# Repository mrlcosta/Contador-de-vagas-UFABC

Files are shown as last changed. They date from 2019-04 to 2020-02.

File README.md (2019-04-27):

Este projeto tem o propósito de auxiliar e humanizar o trabalho dos funcionários da portaria. 
A situação atual é: um senhor de idade avançada que fica encarregado de fazer a contagem de aproximadamente 150 vagas em um caderninho, precisa colocar e tirar o cone para impedir a passagem de carros (embaixo de sol e chuva) e também escuta reclamação de aluno dizendo que as vagas estão sendo contadas erradas (há diversos posts no grupo também).

O projeto é simples: o sensor conta quantos carros entram e quantos carros saem. 
Quando o estacionamento estiver cheio, a fita de led mudará de verde para vermelho.

Assim o senhor da portaria poderá ficar dentro de sua sala apenas verificando as carteirinhas.
Peço a colaboração de todos.

**CONTRIBUIÇÃO**

O projeto aceita contribuição e é open source, porém você precisa seguir as regras abaixo:

Testar bem antes de colocar em prod. Você precisa abranger muitos fatores e todo código deve ser rigorosamente testado para ter o pull request aceito.

O projeto deve possuir o mínimo de boas práticas de código e prezar pelo entendimento alheio. No futuro outras pessoas irão dar manutenção nele, seja gentil.

OBS: A ideia inicial era apenas usar o github como plataforma de versionamento, não imaginei que muitas pessoas gostariam de contribuir, portanto a documentação ainda está muito precária. Estou atualizando aos poucos para que todos possam entender melhor.

A escolha do chip talvez não tenha sido a melhor em questões de popularidade, porém pode ser interessante aprender a mexer em outro microcontrolador. Quem quiser me chamar para perguntar como instala os programas utilizados, compilador, onde conseguir o chip, etc Estarei a disposição. Em breve será documentado.

Muitas pessoas adoram o arduino por ser de fácil acesso, conter muito material didático e as vezes ele acaba ficando na nossa zona de conforto. É interessante levar também para nossa universidade a diversidade de outras ferramentas que não a utilização de arduino, tudo bem? não se sinta acanhado com isto, estamos aqui para expandir nossos horizontes.

**FUNCIONAMENTO BASICO**

Ficará um sensor no portão de entrada e outro no portão de saída.
Quando o sensor detectar que tem um obstáculo na portaria, ele conta ou subtrai uma vaga.
para diferenciar acionamento de humanos ou carros passando o algoritmo de debounce foi implementado.
A cada atualização do numero de carros, o número é atualizado na eeprom para evitar percas por desligamento.
A gravação da eeprom da eeprom é feita de forma rotativa pois ela tem vida útil limitada.

**MATERIAIS MINIMOS**

sensor: http://www.baudaeletronica.com.br/sensor-de-proximidade-infravermelho-e18-d80nk.html

display LCD: http://www.baudaeletronica.com.br/display-lcd-16x2-azul.html

microcontrolador: https://produto.mercadolivre.com.br/MLB-1218797200-modulo-desenvolvimento-microcontrolador-st-stm8-stm8s003f3p6-_JM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

gravador/debuger: https://produto.mercadolivre.com.br/MLB-1132196907-programador-stm32-stm8-stlink-st-link-v2-mini-_JM

A placa irá comutar a fita de led através de um TIP41.

A caixa plastica é um modelo da patola: PB107.

Os botões de navegação são 3 push button.

Dúvidas? Sugesões? fala comigo: mrlcosta0@gmail.com

Seu feedback e engajamento é muito importante pra mim.

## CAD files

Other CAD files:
firmware/ac01.stp
firmware/ac01_Programmer/ac01_STVP.stp

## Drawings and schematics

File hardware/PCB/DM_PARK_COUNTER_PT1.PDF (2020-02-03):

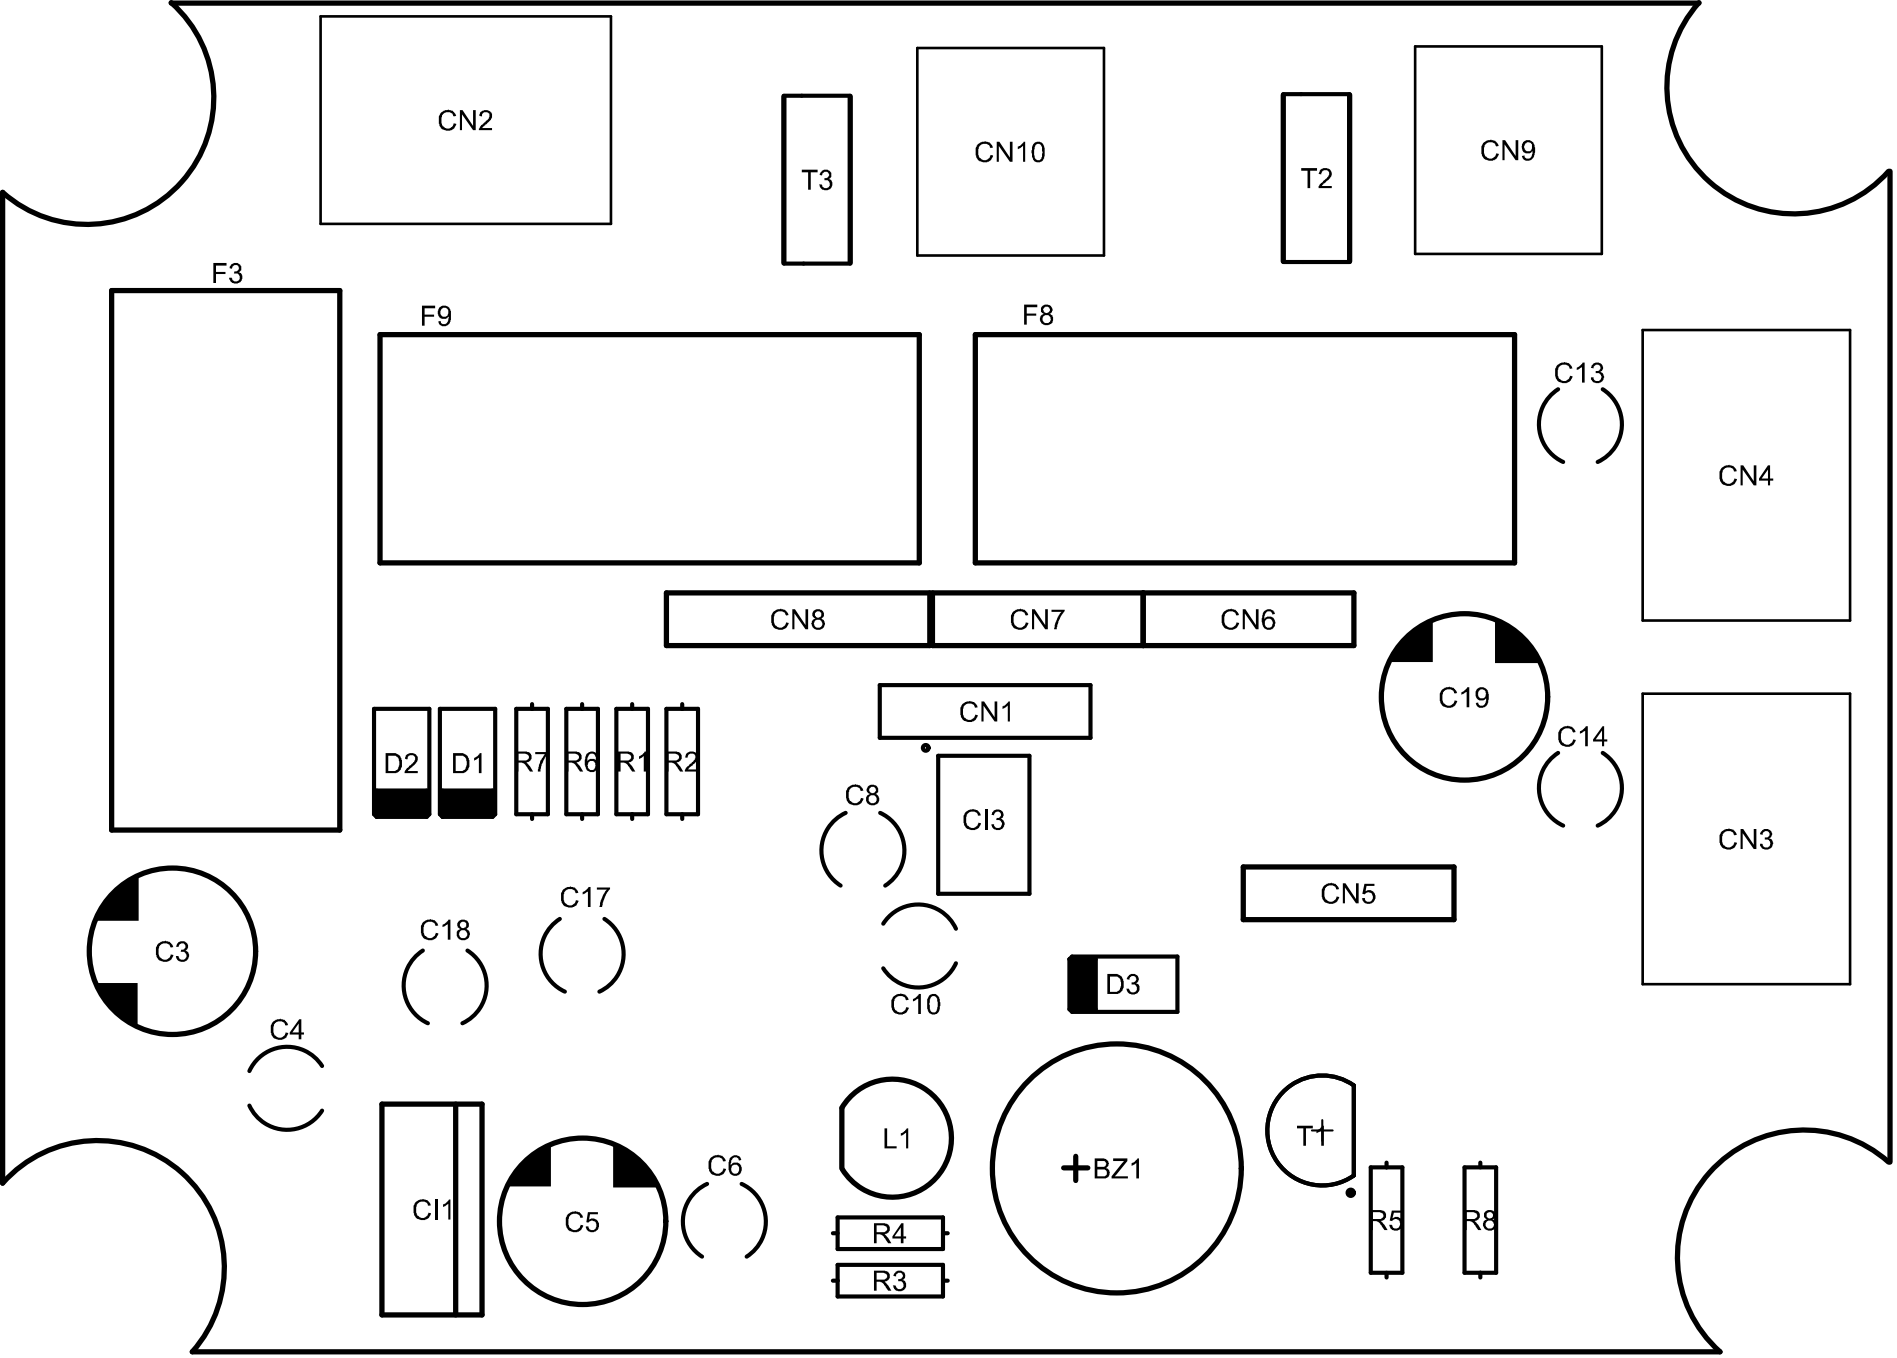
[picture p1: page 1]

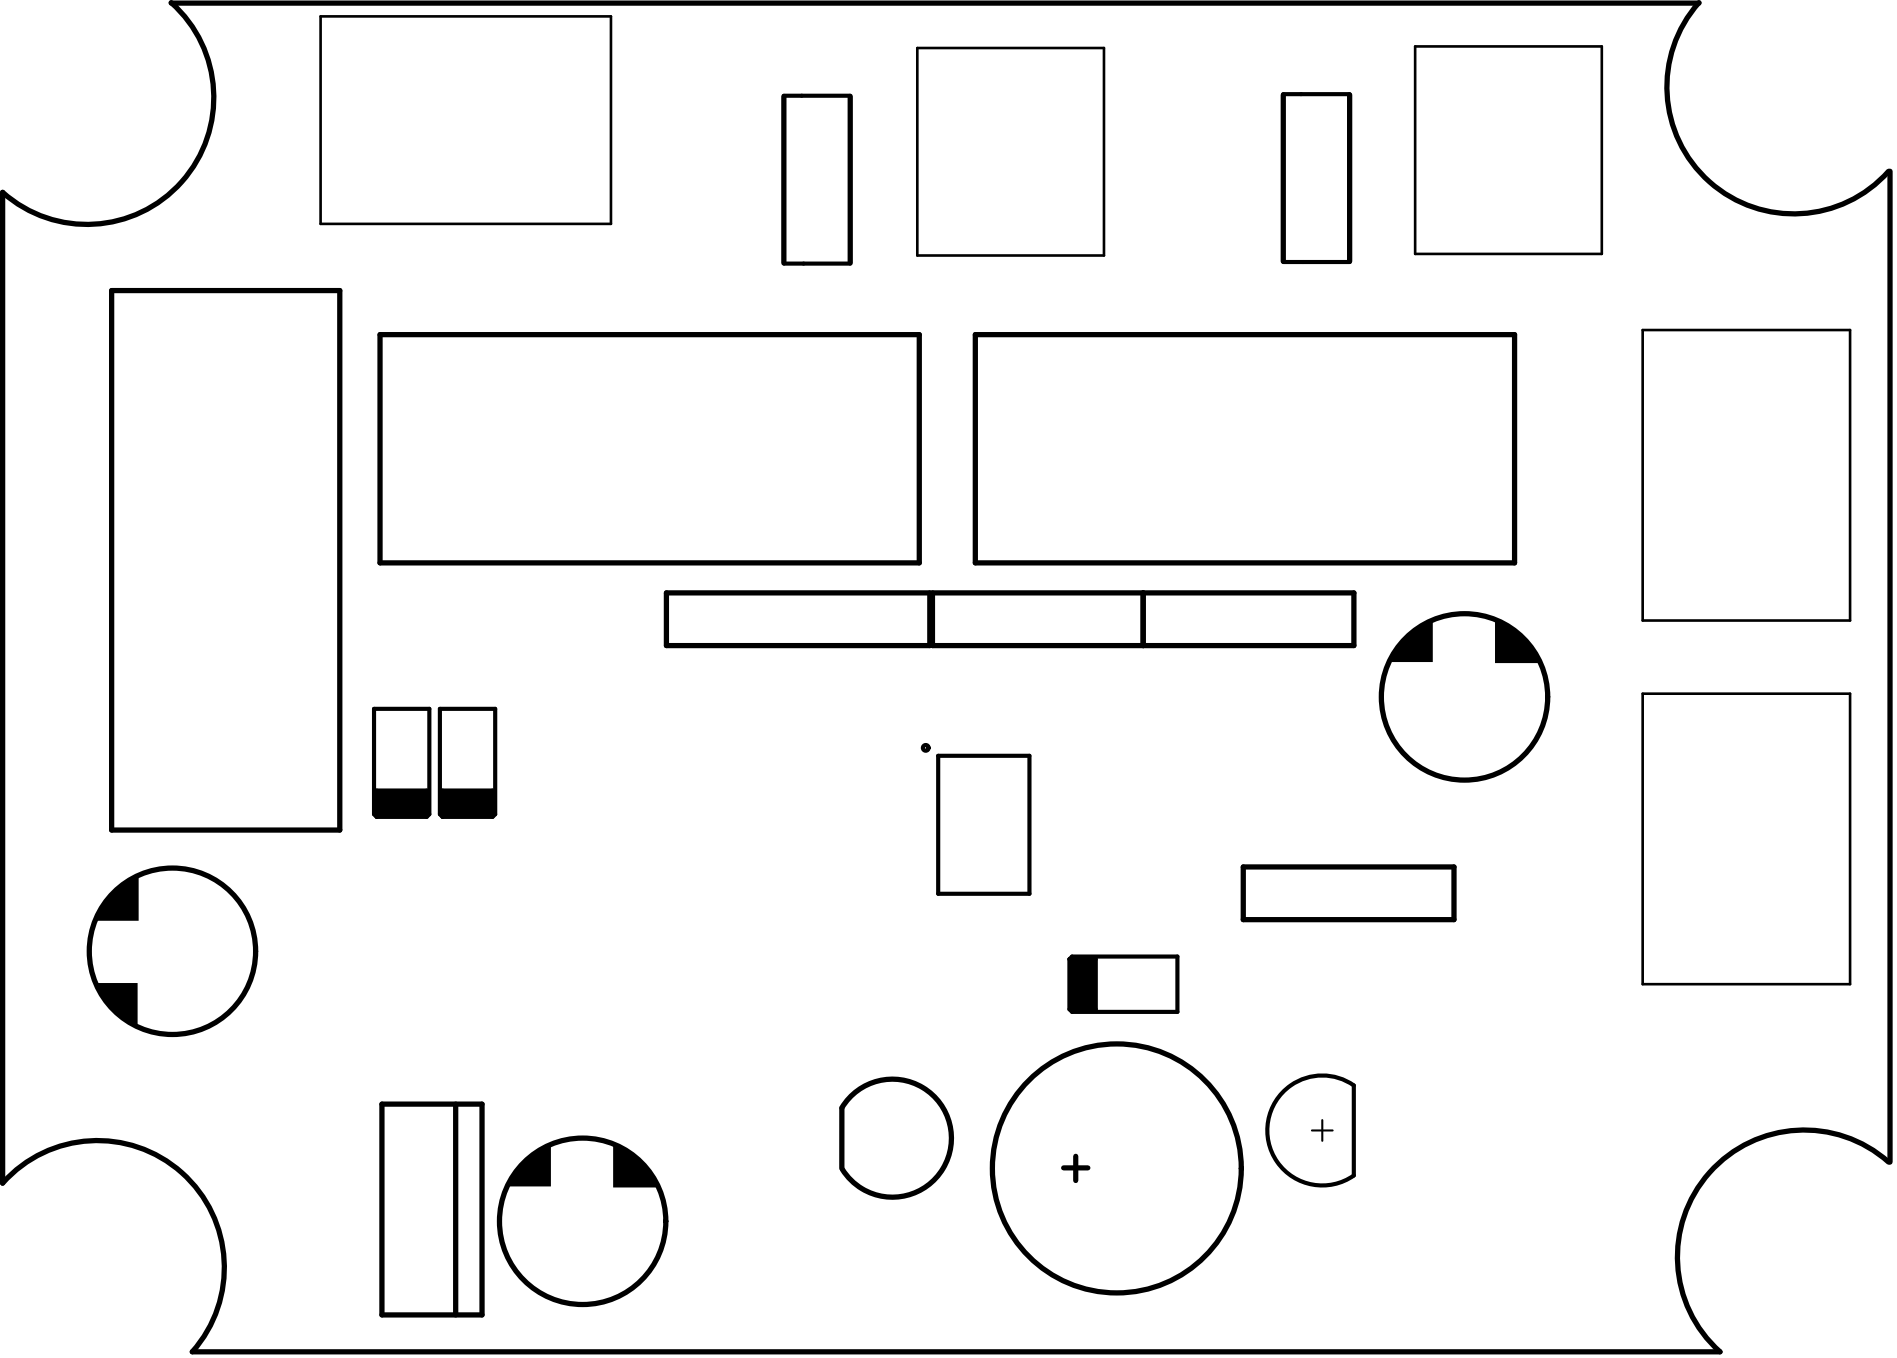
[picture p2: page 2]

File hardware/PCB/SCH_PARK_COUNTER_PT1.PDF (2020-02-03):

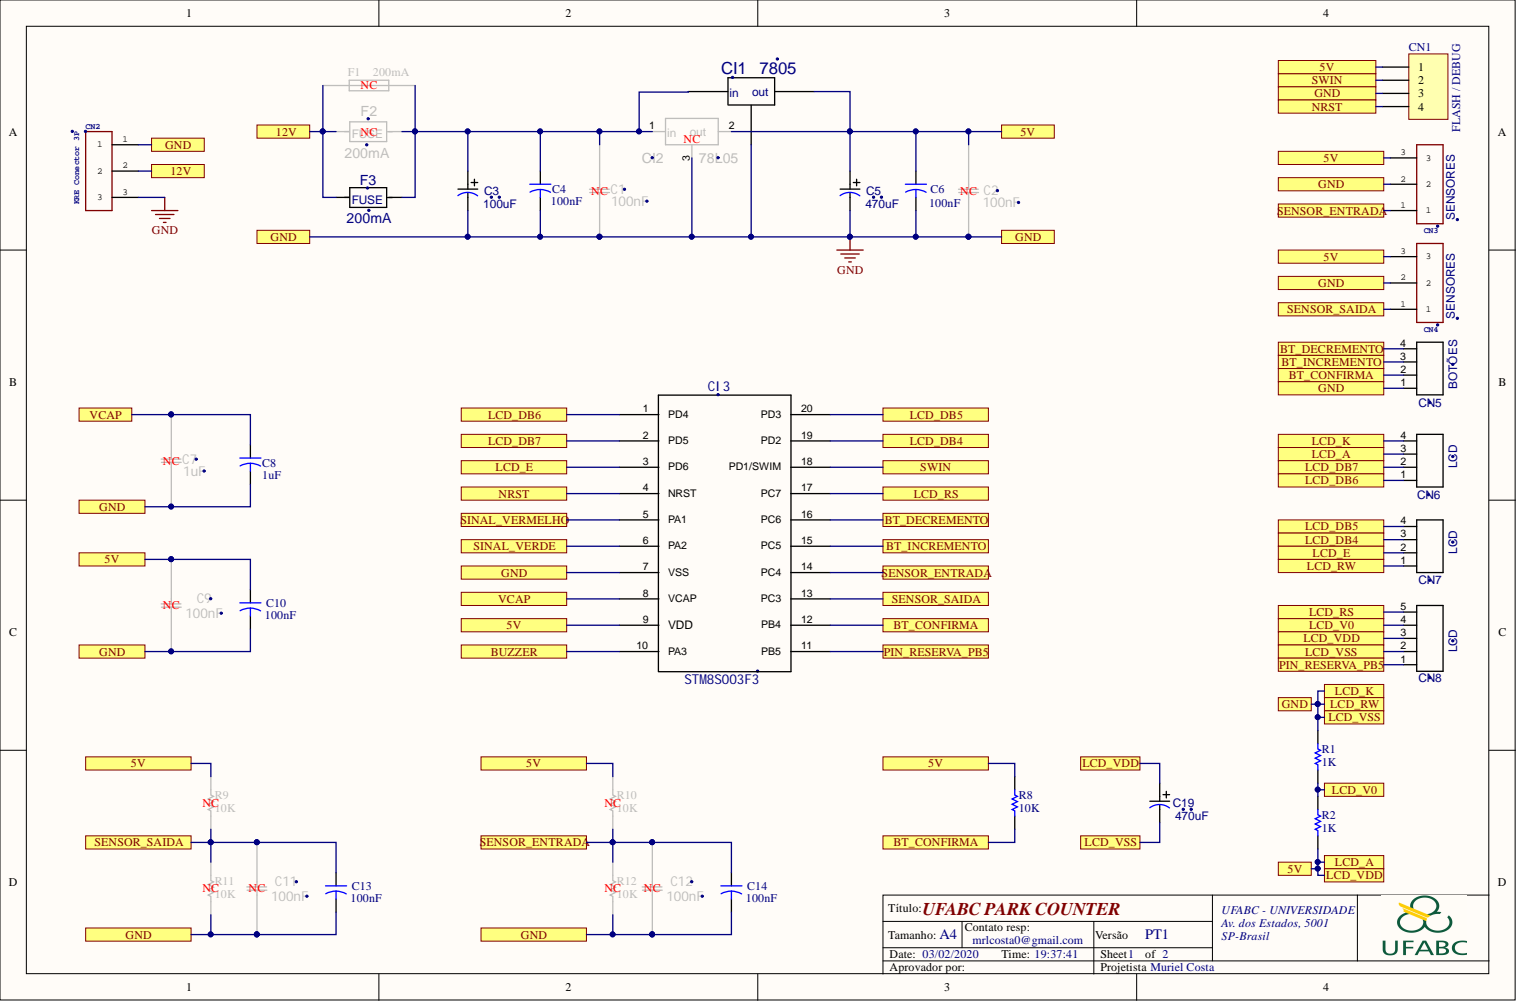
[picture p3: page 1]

Título: UFABC PARK COUNTER | UFABC - UNIVERSIDADE Av. dos Estados, 5001 SP-Brasil
A4 Tamanho: | Contato resp: mrlcosta0@gmail.com | Versão PT1

Date: 03/02/2020 Time: 19:37:41 | | Sheet 1 of 2
Aprovador por: | Projetista Muriel Costa

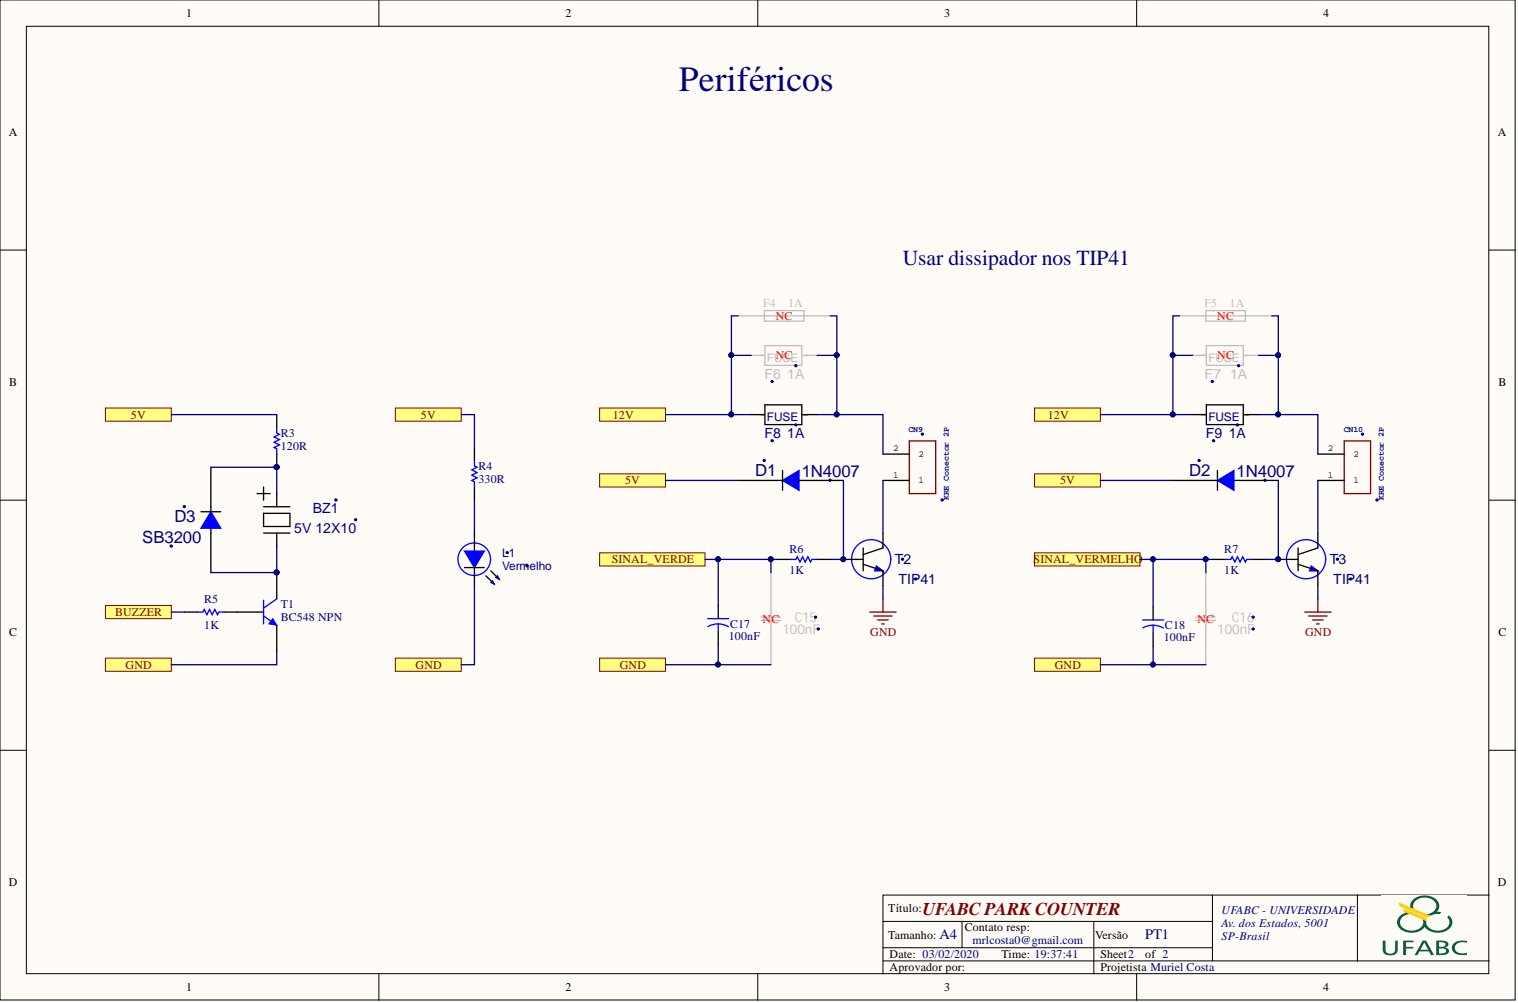
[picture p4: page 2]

T í t u l o : UFABC PARK CO UNTER | UFA BC - UNIVER SIDA D E A v. d o s E s t a d o s, 5 0 0 1 S P-B r a s i l
4 Taman h o : A | Co n tat o res p : mrlco s ta0@gmai l.co m | Vers ã o PT1

Date: Apro 0 3 / 0 2 / 2 0 2 0 T ime: 1 9 : 3 7 : 4 1 | | Sheet 2 o f 2
vad or p or: | Projet i s t a Muriel Co s t a

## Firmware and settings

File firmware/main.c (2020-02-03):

/* MAIN.C file
 *
 * 	Projeto contador de carros para o estacionamento
 * da universidade federal do ABC. 
 * 
 * Com muito carinho
 * Muriel Costa 
 * 2019
 */

#include "stm8s.h"
#include "stm8s_flash.h"
#include "main.h"
#include "stdio.h"

/******************************************************************************
 * Declaração de variáveis globais:                                           *
 ******************************************************************************/
 
uint8_t		controle															= 0;
uint8_t		carros 																= 1;
uint8_t		quantidade_vagas 											= 1;
uint8_t		controle_buzzer 											= 0;
uint8_t		modo_operacao													= TRAVA;

uint16_t	n																			= 0;
uint16_t	contador_debounce_sensor_entrada			= 0;
uint16_t	contador_debounce_sensor_saida				= 0;
uint16_t	contador_debounce_bt_incremento				= 0;
uint16_t	contador_debounce_bt_decremento				= 0;
uint16_t	contador_debounce_bt_confirma					= 0;
uint16_t	contador_delay												= 0;
uint16_t	contador_buzzer												= 0;
uint16_t	tempo_buzzer_incremento								= 0;
uint16_t	tempo_buzzer_decremento								= 0;

uint32_t	eeprom																=	PRIMEIRO_ENDERECO_EEPROM;		//PRIMEIRO_ENDERECO_EEPROM; 

char			buf_carros[3];
char			buf_vagas[3];

bool			sensor_entrada												= 0;
bool			last_sensor_entrada										= 0;
bool			sensor_saida													= 0;
bool			last_sensor_saida											= 0;
bool			bt_incremento													= 0;
bool			last_bt_incremento										= 0;
bool			bt_decremento													= 0;
bool			last_bt_decremento										= 0;
bool			bt_confirma														= 0;
bool			last_bt_confirma											= 0;
bool			display_carros_atualizado							= 0;
bool			display_vagas_atualizado							= 0;
bool			buzzer_incremento											= 0;
bool			buzzer_decremento											= 0;

/******************************************************************************
 * Funções e Procedimentos                                                    *
 ******************************************************************************/
void timerInit								(void);
void adcInit									(void);
void ioInit										(void);
void commInit									(void);
void lcdInit									(void);
void uartInit									(void);
void uartDeInit								(void);

void atualiza_menu						(void);
void atualiza_display_carros	(void);
void atualiza_display_vagas		(void);
void leitura_comunicacao			(void);
void delay										(int delay);
void sinaliza_semaforo				(void);
void checa_botao							(void);
void checa_entradas						(void);
void contagem_carros					(void);
void contagem_estacionamento	(void);
void checa_eeprom							(void);
void grava_eeprom							(void);
void sinalizacao_buzzer 			(void);
void incrementa_buzzer 				(void);
void decrementa_buzzer 				(void);

void lcd_clear								(void);
void lcd_write_string					(const uint8_t *string);
void lcd_set_line							(uint8_t line);
void lcd_write								(uint8_t data, uint8_t type);
void lcd_write_nibble					(uint8_t data, uint8_t type);
void mensagem_inicial_lcd			(void);


/******************************************************************************
 * Loop principal:                                                            *
 ******************************************************************************/
main(){
	CLK->CKDIVR = 0; 
	ioInit();
	timerInit();
	FLASH_DeInit();
	enableInterrupts();
	lcdInit();
	lcd_clear();
	mensagem_inicial_lcd();
	checa_eeprom();
	delay(2500);
	lcd_clear();
	
	while (1){
		checa_entradas();
		contagem_carros();
		contagem_estacionamento();
		sinalizacao_buzzer();
		atualiza_display_carros();
		atualiza_display_vagas();
		sinaliza_semaforo();
	}
}

void sinaliza_semaforo(){
	
	if(carros<quantidade_vagas){
		GPIO_WriteHigh(SINAL_VERDE);
		GPIO_WriteLow(SINAL_VERMELHO);
	}else{
		GPIO_WriteLow(SINAL_VERDE);
		GPIO_WriteHigh(SINAL_VERMELHO);
	}
	
}



/*******************************************************************************
 * atualiza_display_carros();                                                  *
 *                                                                             *
 * Procedimento de atualização do numero de carros no display;                 *
 *                                                                             *
 * void -> não retorna valor;                                                  *
 ******************************************************************************/
void atualiza_display_carros(void){
	
	if(display_carros_atualizado){return;}
	
	sprintf(buf_carros, "%03d", (int) carros-1 );
	lcd_write(LINE_1, FALSE);
	lcd_write_string	 ("CARROS: ");
	lcd_write(buf_carros[0],TRUE);
	lcd_write(buf_carros[1],TRUE);
	lcd_write(buf_carros[2],TRUE);
	if (modo_operacao == CARROS){
		lcd_write_string	 (" <--");
	}
	display_carros_atualizado = TRUE;
}

/*******************************************************************************
 * atualiza_display_vagas();                                                   *
 *                                                                             *
 * Procedimento de atualização do numero de vagas no display;                  *
 *                                                                             *
 * void -> não retorna valor;                                                  *
 ******************************************************************************/
void atualiza_display_vagas(void){
	
	if(display_vagas_atualizado){return;}
	
	sprintf(buf_vagas, "%03d", (int) quantidade_vagas-1 );
	lcd_write(LINE_2, FALSE);
	lcd_write_string	 ("VAGAS : ");
	lcd_write(buf_vagas[0],TRUE);
	lcd_write(buf_vagas[1],TRUE);
	lcd_write(buf_vagas[2],TRUE);
	
	if (modo_operacao == VAGAS){
		lcd_write_string	 (" <--");
	}
	
	display_vagas_atualizado = TRUE;
}

/*******************************************************************************
 * delay();                                                   								 *
 *                                                                             *
 * Procedimento de delay;                 	 																	 *
 *                                                                             *
 * int delay -> valor em milisegundos de pausa;    														 *
 * void   -> não retorna valor																								 *
 ******************************************************************************/
void delay(int delay){
	uint16_t tempo_atual_delay = contador_delay;
	while(tempo_atual_delay + delay >= contador_delay){nop();}
}

/*******************************************************************************
 * contagem_estacionamento();                                                  *
 *                                                                             *
 * Procedimento de tratamento do estado dos botoes e vagas/carros no display;  *
 *                                                                             *
 * void -> não retorna valor;                                                  *
 ******************************************************************************/
void contagem_estacionamento(){
	
	if(last_bt_confirma != bt_confirma){
		last_bt_confirma 	= bt_confirma;
		if(bt_confirma){
			display_vagas_atualizado = FALSE;
			display_carros_atualizado = FALSE;
			lcd_clear();
			grava_eeprom();
			if(modo_operacao < 2){
				modo_operacao++;
			}else{
				modo_operacao = 0;
			}
		}
	}
	
	if(	modo_operacao == TRAVA){return;}
	
	if(last_bt_incremento != bt_incremento){
		
		last_bt_incremento 	= bt_incremento;
		if(bt_incremento){
			if (modo_operacao == VAGAS){
				if (quantidade_vagas < 253){
					quantidade_vagas++;
					display_vagas_atualizado = FALSE;
				}
			}else{
				if (carros < 253){
					carros++;
					display_carros_atualizado = FALSE;
				}
			}
			
		}
	}
	
	if(last_bt_decremento != bt_decremento){
		
		last_bt_decremento 	= bt_decremento;
		if(bt_decremento){
			if (modo_operacao == VAGAS){
				if (quantidade_vagas > 1){
					quantidade_vagas--;
					display_vagas_atualizado = FALSE;
				}
			}else{
				if (carros > 1){
					carros--;
					display_carros_atualizado = FALSE;
				}
			}
			
		}
	}
	
}

/*******************************************************************************
 * incrementa_buzzer();                                                        *
 *                                                                             *
 *	Procedimento de atualizar flag do buzzer para entrada de carro no 				 *
 *estacionamento;              																								 *
 *																																						 *
 * void -> não retorna valor;                                                  *
 ******************************************************************************/
void incrementa_buzzer (){
	buzzer_incremento = TRUE;
	tempo_buzzer_incremento = contador_buzzer;
}

/*******************************************************************************
 * decrementa_buzzer();                                                        *
 *                                                                             *
 * Procedimento de atualizar flag do buzzer para saída de carro no 						 *
 *estacionamento;  	     																											 *
 *                                                                             *
 * void -> não retorna valor;                                                  *
 ******************************************************************************/
void decrementa_buzzer (){
	buzzer_decremento = TRUE;
	tempo_buzzer_decremento = contador_buzzer;
}

/*******************************************************************************
 * sinalizacao_buzzer();                                                       *
 *                                                                             *
 * Procedimento de tocar buzzer para saída ou entrada de carro no 						 *
 *estacionamento;  	     																											 *
 *                                                                             *
 * void -> não retorna valor;                                                  *
 ******************************************************************************/
void sinalizacao_buzzer (){
	if (buzzer_incremento){
		
		GPIO_WriteHigh(BUZZER);
		if (contador_buzzer-tempo_buzzer_incremento <= TEMPO_BUZZER_INCREMENTO){return;}
		GPIO_WriteLow(BUZZER);
		buzzer_incremento = FALSE;
		controle_buzzer = 0;
	}
	
	if (buzzer_decremento){
		
		GPIO_WriteHigh(BUZZER);
		if (contador_buzzer-tempo_buzzer_decremento <= TEMPO_BUZZER_DECREMENTO){return;}
		GPIO_WriteLow(BUZZER);
		buzzer_decremento = FALSE;
	}
}

/*******************************************************************************
 * checa_eeprom();                                                      	 		 *
 *                                                                             *
 * Procedimento de checagem de eeprom para inicializar a quantidade de carros  *
 *e vagas com ultimo número antes do desligamento															 *
 *                                                                             *
 * void -> não retorna valor;                                                  *
 ******************************************************************************/
void checa_eeprom(){
	
	eeprom = PRIMEIRO_ENDERECO_EEPROM;
	while( (FLASH_ReadByte(eeprom) == 0x00) && (eeprom <= ULTIMO_ENDERECO_EEPROM) ){
		eeprom++;
	}
	
	if(eeprom >= ULTIMO_ENDERECO_EEPROM ){ // se estourou  e não achou nada, volta pro inicio
		eeprom = PRIMEIRO_ENDERECO_EEPROM; 
		carros = FLASH_ReadByte(eeprom);
		quantidade_vagas = FLASH_ReadByte(++eeprom);
	}else{	
		carros = FLASH_ReadByte(eeprom);
		quantidade_vagas = FLASH_ReadByte(++eeprom);
		
	}
}

/*******************************************************************************
 * grava_eeprom();                                                      	 		 *
 *                                                                             *
 * Procedimento de gravação da eeprom com o número de vagas e carros					 *
 *                                                                             *
 * void -> não retorna valor;                                                  *
 ******************************************************************************/
void grava_eeprom(){
	
	FLASH_Unlock(FLASH_MEMTYPE_DATA);
	if(eeprom>=ULTIMO_ENDERECO_EEPROM-1){
		
		eeprom = PRIMEIRO_ENDERECO_EEPROM;
		FLASH_ProgramByte(eeprom, carros);
		FLASH_ProgramByte(++eeprom , quantidade_vagas);
		FLASH_EraseByte(ULTIMO_ENDERECO_EEPROM);
		FLASH_EraseByte(ULTIMO_ENDERECO_EEPROM-1);
		FLASH_EraseByte(ULTIMO_ENDERECO_EEPROM-2);
		
	}else{
		
		FLASH_ProgramByte(++eeprom, carros);
		FLASH_ProgramByte(++eeprom , quantidade_vagas);
		
		if (eeprom >= PRIMEIRO_ENDERECO_EEPROM + 3){
			FLASH_EraseByte(eeprom - 2);
			FLASH_EraseByte(eeprom - 3);
		}
		
	}
	FLASH_Lock(FLASH_MEMTYPE_DATA);
	
}

/*******************************************************************************
 * mensagem_inicial_lcd();                                                     *
 *                                                                             *
 * Mostra a mensagem inicial na tela ao ligar o produto					 							 *
 *                                                                             *
 * void -> não retorna valor;                                                  *
 ******************************************************************************/
void mensagem_inicial_lcd(){
	lcd_write(LINE_1, FALSE);
	lcd_write_string	 ("  UNIVERSIDADE  ");
	lcd_write(LINE_2, FALSE);
	lcd_write_string	 (" FEDERAL DO ABC ");
}

/*******************************************************************************
 * contagem_carros();                                                     		 *
 *                                                                             *
 * trata o acionamento dos sensores para incrementar/decrementar carros				 *
 *                                                                             *
 * void -> não retorna valor;                                                  *
 ******************************************************************************/
void contagem_carros(){
	
	if(last_sensor_entrada != sensor_entrada){
		
		last_sensor_entrada 	= sensor_entrada;
		if(sensor_entrada){
			
			if (carros < 255){
				carros++;
				incrementa_buzzer();
				display_carros_atualizado = FALSE;
			}else{
					// mostra na tela "limite de contagem"
				
			}
			grava_eeprom();
		}
	}
	
	if(last_sensor_saida != sensor_saida){
		
		last_sensor_saida 	= sensor_saida;
		if(sensor_saida){
			if(carros > 0){
				carros--;
				decrementa_buzzer();
				display_carros_atualizado = FALSE;
			}else{
					//mostra na tela "limite de contagem"
				
			}
			grava_eeprom();
		}
	}

}

/*******************************************************************************
 * checa_entradas();                                                           *
 *                                                                             *
 * Procedimento de checagem e debounce do estado dos sensores e botões;        *
 *                                                                             *
 * void -> não recebe parâmetros;                                              *
 *                                                                             *
 * void -> não retorna valor;                                                  *
 ******************************************************************************/
void checa_entradas (void){
	
	/*********************sensor de entrada****************************/
	
	if(!GPIO_ReadInputPin(SENSOR_ENTRADA)){
		
		if(contador_debounce_sensor_entrada >= TEMPO_DEBOUNCE_ACIONA){
			
			sensor_entrada = TRUE;	
			contador_debounce_sensor_entrada = 0;
		}
		
	}else{
		
		if(contador_debounce_sensor_entrada >= TEMPO_DEBOUNCE_DESACIONA){
			
			sensor_entrada = FALSE; 
			contador_debounce_sensor_entrada = 0;
		}
	}
	
	/*********************sensor de saída*****************************/
	
	if(!GPIO_ReadInputPin(SENSOR_SAIDA)){
		
		if(contador_debounce_sensor_saida >= TEMPO_DEBOUNCE_ACIONA){
			
			sensor_saida = TRUE;	
			contador_debounce_sensor_saida = 0;
		}
		
	}else{
		
		if(contador_debounce_sensor_saida >= TEMPO_DEBOUNCE_DESACIONA){
			
			sensor_saida = FALSE; 
			contador_debounce_sensor_saida = 0;
		}
	}
	
	/*********************botão de incremento*****************************/
	
	if(!GPIO_ReadInputPin(BT_INCREMENTO)){
		
		if(contador_debounce_bt_incremento >= TEMPO_DEBOUNCE_BT_INCREMENTO){
			
			bt_incremento = TRUE;	
			contador_debounce_bt_incremento = 0;
		}
		
	}else{
		
		if(contador_debounce_bt_incremento >= TEMPO_DEBOUNCE_BT_INCREMENTO){
			
			bt_incremento = FALSE; 
			contador_debounce_bt_incremento = 0;
		}
	}
	
	/*********************botão de decremento*****************************/
	
	if(!GPIO_ReadInputPin(BT_DECREMENTO)){
		
		if(contador_debounce_bt_decremento >= TEMPO_DEBOUNCE_BT_DECREMENTO){
			 
			bt_decremento = TRUE;	
			contador_debounce_bt_decremento = 0;
		}
		
	}else{
		
		if(contador_debounce_bt_decremento >= TEMPO_DEBOUNCE_BT_DECREMENTO){
		
			bt_decremento = FALSE; 
			contador_debounce_bt_decremento = 0;
		}
	}
	
	/*********************botão de confirmação*****************************/
	
	if(!GPIO_ReadInputPin(BT_CONFIRMA)){
		
		if(contador_debounce_bt_confirma >= TEMPO_DEBOUNCE_BT_CONFIRMA){
			 
			bt_confirma = TRUE;	
			contador_debounce_bt_confirma = 0;
		}
		
	}else{
		
		if(contador_debounce_bt_confirma >= TEMPO_DEBOUNCE_BT_CONFIRMA){
		
			bt_confirma = FALSE; 
			contador_debounce_bt_confirma = 0;
		}
	}
	
}

/*******************************************************************************
 * void ioInit(void);                                                          *
 *                                                                             *
 * Inicialização dos IO's                                                      *
 *                                                                             *
 ******************************************************************************/
void ioInit(void){	 

	GPIO_Init(BT_INCREMENTO,  	GPIO_MODE_IN_PU_NO_IT);
	GPIO_Init(BT_DECREMENTO,  	GPIO_MODE_IN_PU_NO_IT);
	GPIO_Init(BT_CONFIRMA,  		GPIO_MODE_IN_PU_NO_IT);
	
	GPIO_Init(SENSOR_SAIDA,  		GPIO_MODE_IN_PU_NO_IT);
	GPIO_Init(SENSOR_ENTRADA,		GPIO_MODE_IN_PU_NO_IT);
	
	GPIO_Init(BUZZER,    				GPIO_MODE_OUT_PP_LOW_SLOW);
	GPIO_Init(SINAL_VERMELHO,   GPIO_MODE_OUT_PP_LOW_SLOW);
	GPIO_Init(SINAL_VERDE,    	GPIO_MODE_OUT_PP_LOW_SLOW);
	 
	GPIO_Init(LCD_E,    				GPIO_MODE_OUT_PP_LOW_SLOW);
	GPIO_Init(LCD_RS,  				 	GPIO_MODE_OUT_PP_LOW_SLOW);
	GPIO_Init(LCD_DB4,  				GPIO_MODE_OUT_PP_LOW_SLOW);
	GPIO_Init(LCD_DB5,  				GPIO_MODE_OUT_PP_LOW_SLOW);
	GPIO_Init(LCD_DB6,  				GPIO_MODE_OUT_PP_LOW_SLOW);
	GPIO_Init(LCD_DB7,  				GPIO_MODE_OUT_PP_LOW_SLOW);
}

/*******************************************************************************
* timerInit();                                                                 *
*                                                                              *
* Procedimento de configuração de Timer                                        *
*                                                                              *
* void -> não recebe parâmetros;                                               *
*                                                                              *
* void -> não retorna valor;                                                   *
*                                                                              *
* Configurações de Timer:                                                      *
*                                                                              *
* Timer 4:                                                                     *
* Prescaler = 64                                                               *
* Overflow  = 250                                      									       *
*                                                     									       *
* T = PRESCALER * OVERFLOW / FREQUENCIA DE CLOCK                               *
*                                                                              *
* T = 64 * 250 / 16.000.000 = 1ms                                              *
*                                                                              *
*******************************************************************************/
void timerInit(void){
	TIM4_DeInit      ();                       
	TIM4_TimeBaseInit(TIM4_PRESCALER_64, 249); 	
	TIM4_ITConfig    (TIM4_IT_UPDATE, ENABLE);
	TIM4_Cmd         (ENABLE);
}
	
/*******************************************************************************
 * lcdInit();                                                                  *
 *                                                                             *
 * Inicialização do Display;                                                   *
 *                                                                             *
 * void -> não recebe parâmetros;                                              *
 *                                                                             *
 * void -> não retorna valor;                                                  *
 ******************************************************************************/
void lcdInit(void){
	GPIO_WriteLow(LCD_RS);
	GPIO_WriteLow(LCD_E);   
	 
	for(n = 0; n < 50000; n++){ nop(); }
	for(n = 0; n < 50000; n++){ nop(); }
	 
	lcd_write_nibble(0x03, FALSE);	 
	lcd_write_nibble(0x03, FALSE); 
	 
	lcd_write(0x02, FALSE); //set to 4 bit interface, 1 line and 5*7 font
	lcd_write(0x28, FALSE); //set to 4 bit interface, 2 line and 5*10 font
	lcd_write(0x0C, FALSE); //set to 4 bit interface, 2 line and 5*7 font
	lcd_write(0x01, FALSE); //clear display
	lcd_write(0x06, FALSE); //move cursor right after write
}
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

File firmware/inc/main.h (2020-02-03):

/*******************************************************************************
* GPIO:                                                                        *
*******************************************************************************/

#define LCD_PORT    		GPIOD

#define	SINAL_VERMELHO	GPIOA, GPIO_PIN_1
#define	SINAL_VERDE			GPIOA, GPIO_PIN_2
#define	BUZZER        	GPIOA, GPIO_PIN_3
//#define             	GPIOA, GPIO_PIN_4
//#define             	GPIOA, GPIO_PIN_5
//#define       				GPIOA, GPIO_PIN_6

//#define             	GPIOB, GPIO_PIN_0
//#define             	GPIOB, GPIO_PIN_1
//#define             	GPIOB, GPIO_PIN_2
//#define      					GPIOB, GPIO_PIN_3
#define	BT_CONFIRMA     GPIOB, GPIO_PIN_4 //sem diodo pro vdd
//#define	     					GPIOB, GPIO_PIN_5
//#define             	GPIOB, GPIO_PIN_6
//#define             	GPIOB, GPIO_PIN_7

//#define        				GPIOC, GPIO_PIN_1
//#define          			GPIOC, GPIO_PIN_2
#define SENSOR_SAIDA 		GPIOC, GPIO_PIN_3
#define SENSOR_ENTRADA  GPIOC, GPIO_PIN_4
#define BT_INCREMENTO  	GPIOC, GPIO_PIN_5
#define BT_DECREMENTO  	GPIOC, GPIO_PIN_6
#define LCD_RS       		GPIOC, GPIO_PIN_7

//#define        				GPIOD, GPIO_PIN_0
//#define	     					GPIOD, GPIO_PIN_1 //Swim
#define LCD_DB4     		GPIOD, GPIO_PIN_2
#define LCD_DB5     		GPIOD, GPIO_PIN_3
#define LCD_DB6     		GPIOD, GPIO_PIN_4
#define LCD_DB7     		GPIOD, GPIO_PIN_5
#define	LCD_E      			GPIOD, GPIO_PIN_6
//#define       				GPIOD, GPIO_PIN_7

//#define             	GPIOE, GPIO_PIN_0
//#define             	GPIOE, GPIO_PIN_1
//#define             	GPIOE, GPIO_PIN_2
//#define             	GPIOE, GPIO_PIN_3
//#define          			GPIOE, GPIO_PIN_5
//#define        				GPIOE, GPIO_PIN_6
//#define       				GPIOE, GPIO_PIN_7

//#define         			GPIOG, GPIO_PIN_0
//#define             	GPIOG, GPIO_PIN_1

/*******************************************************************************
* MODOS DE OPERAÇÃO:                                                           *
*******************************************************************************/
#define	TRAVA		0
#define	VAGAS		1
#define	CARROS	2

/*******************************************************************************
* EEPROM:                                                                      *
*******************************************************************************/
#define PRIMEIRO_ENDERECO_EEPROM			0x4000
#define ULTIMO_ENDERECO_EEPROM				0x427f

/*******************************************************************************
* BOOL:                                                                      *
*******************************************************************************/
#define TRUE 		1
#define FALSE 	0

/*******************************************************************************
* TIMER:                                                                       *
*******************************************************************************/
#define TEMPO_DEBOUNCE_ACIONA   			700
#define TEMPO_DEBOUNCE_DESACIONA			100
#define	TEMPO_DEBOUNCE_BT_INCREMENTO	30
#define	TEMPO_DEBOUNCE_BT_DECREMENTO	30
#define	TEMPO_DEBOUNCE_BT_CONFIRMA		30
#define	TEMPO_BUZZER_INCREMENTO				500
#define	TEMPO_BUZZER_DECREMENTO				100


/*******************************************************************************
* LCD:                                                                       	 *
*******************************************************************************/
#define LCD_16X4
	
#ifdef 	LCD_16X4

#define LINE_1 0x80
#define LINE_2 0xC0
#define LINE_3 0x90
#define LINE_4 0xD0

#endif

#ifdef 	LCD_20X4

#define LINE_1 0x80
#define LINE_2 0xC0
#define LINE_3 0x94
#define LINE_4 0xD4

#endif

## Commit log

2019-04-24 push inicial do projeto
    [ac01.stp, ac01_STVP.stp]
2019-04-26 inserindo hardware
    [PARK_COUNTER_PT1.PcbDoc, PARK_COUNTER_PT1.PrjPCB, PARK_COUNTER_PT1_1.SchDoc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]
2019-04-26 atualizacao de README.md
2019-04-26 inserindo esquema eletrico da placa em pdf
    [PARK_COUNTER_PT1.PcbDoc, PARK_COUNTER_PT1.PrjPCB, PARK_COUNTER_PT1_1.SchDoc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]
2019-04-26 Alteração de FW
2019-04-27 Atualizacao de HW
    [PARK_COUNTER_PT1.PrjPCB, PARK_COUNTER_PT1_1.SchDoc, PARK_COUNTER_PT1_2.SchDoc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]
2019-05-02 Atualizacao de HW e FW
    [PARK_COUNTER_PT1_1.SchDoc, PARK_COUNTER_PT1_2.SchDoc, PARK_COUNTER_PT1_UN.PcbDoc]
2020-02-03 Atualizacao de PCB
    [PARK_COUNTER_PT1.PrjPCB, PARK_COUNTER_PT1_1.SchDoc, PARK_COUNTER_PT1_UN.PcbDoc]
